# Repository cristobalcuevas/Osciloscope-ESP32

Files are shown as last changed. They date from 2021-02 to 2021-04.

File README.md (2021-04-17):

# Osciloscope with ESP32

This was my project to get my degree :)

It was based on designing a board that could do the acquisition and conditioning of analog signals so that later they would be read by the ESP32 and displayed on a local server within the memory of the ESP32, so that several devices could access through the IP simultaneously.

## Circuit

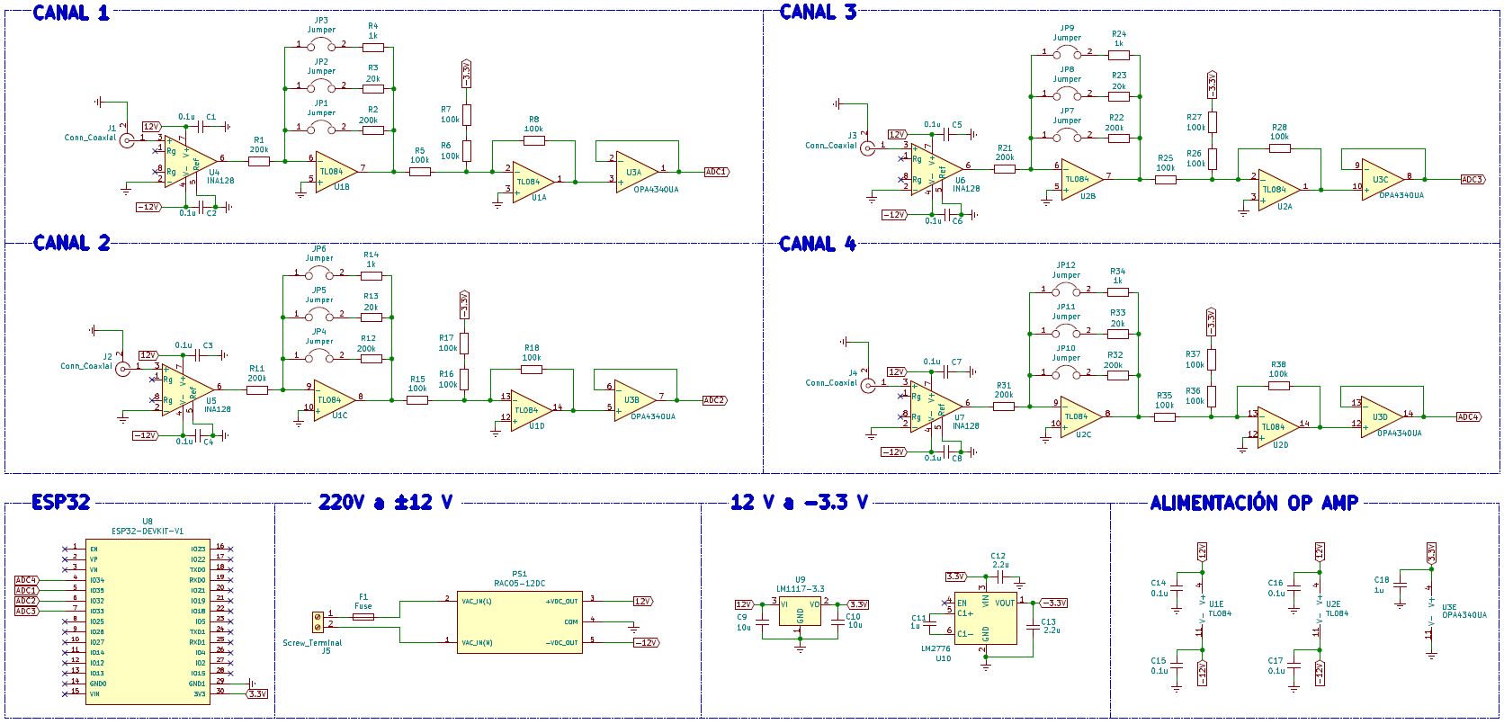
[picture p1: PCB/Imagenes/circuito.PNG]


## PCB Design

### Front Layer
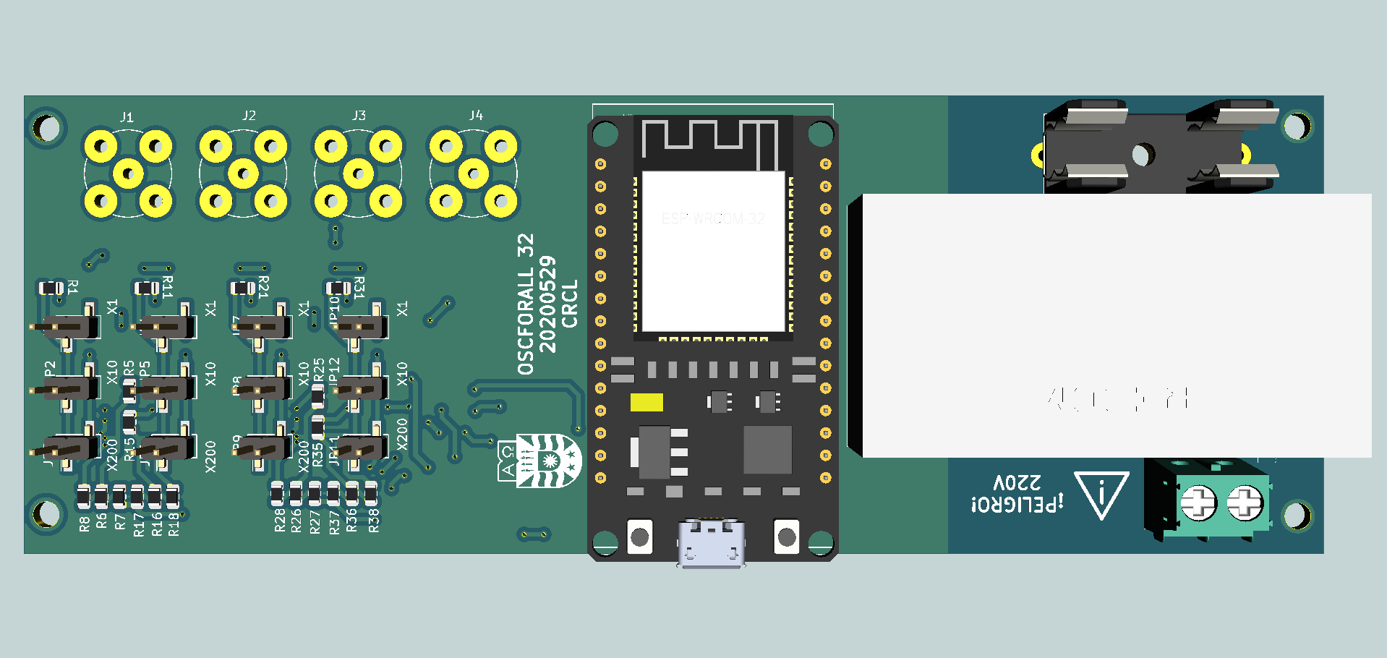
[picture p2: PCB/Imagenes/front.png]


### Back Layer
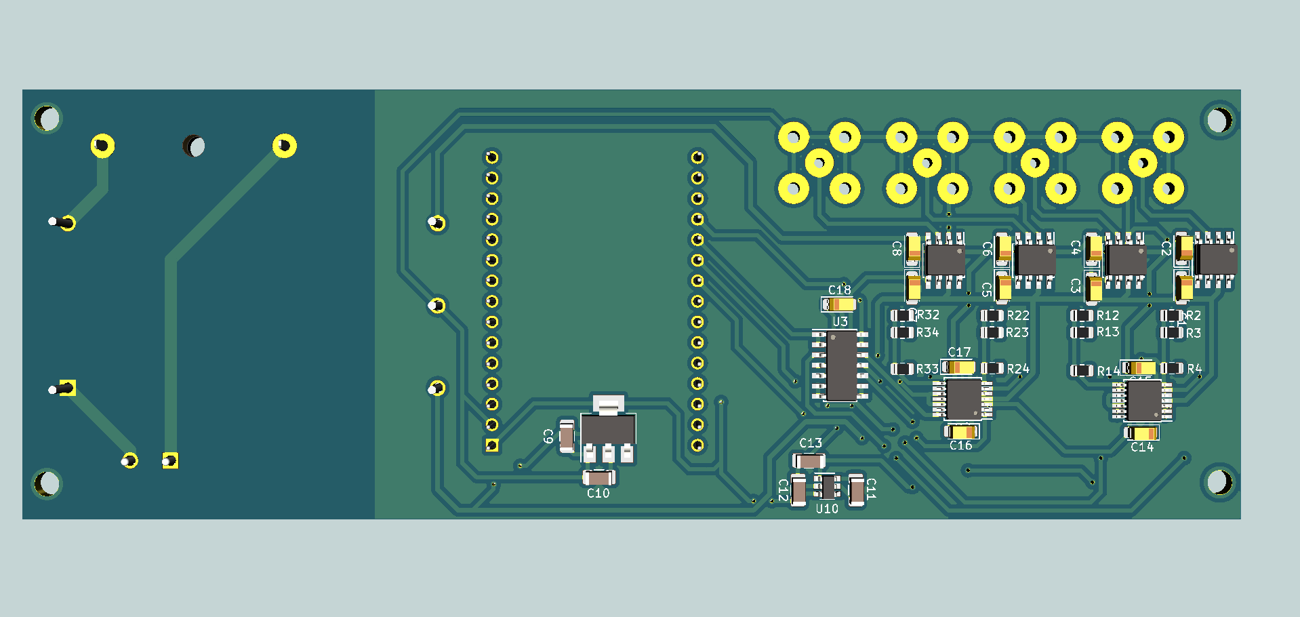
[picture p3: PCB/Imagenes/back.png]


## Video

<a href="https://drive.google.com/file/d/1jKXpbea2SFpHbxWFMag4WS3YogWa_oBE/view?usp=sharing" target="_blank">Video Google Drive</a>

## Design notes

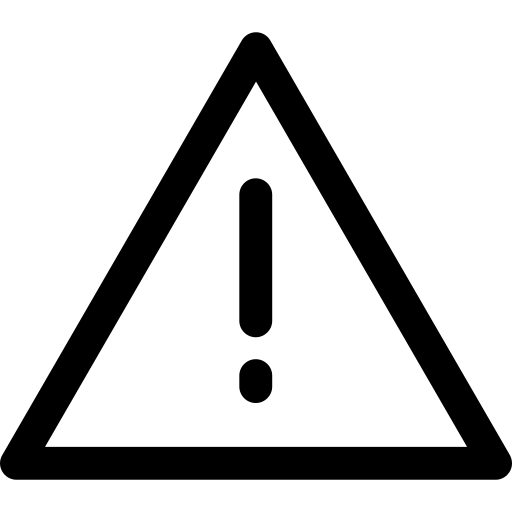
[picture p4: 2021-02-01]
PCB/Graficas/Peligro/Peligro.bmp

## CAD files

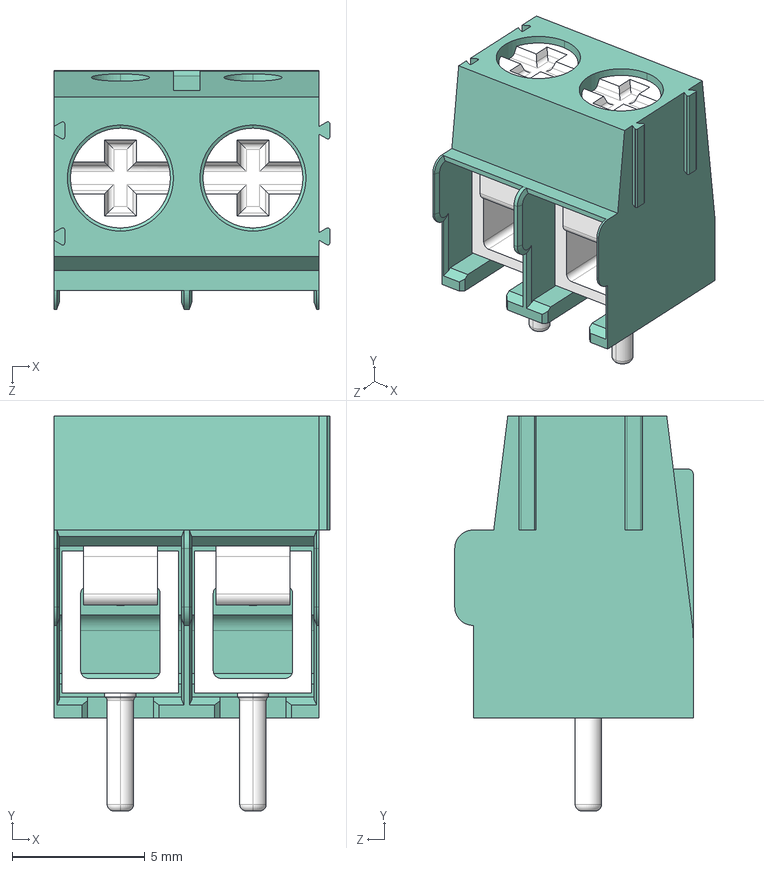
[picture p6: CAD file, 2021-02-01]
PCB/3D/Terminal_Bloc.STEP
10.4 x 14.9 x 9.00 mm

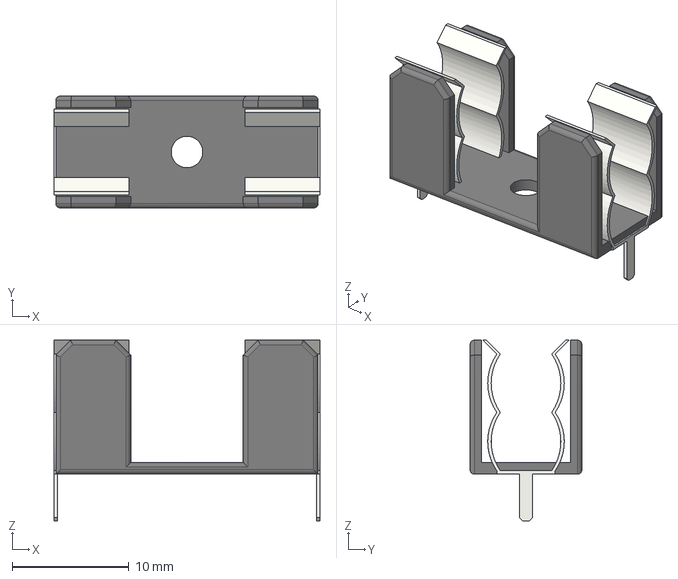
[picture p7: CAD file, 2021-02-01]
PCB/3D/Fuseholder_Cylinder-5x20mm_Schurter_0031_8201_Horizontal_Open.step
22.8 x 9.60 x 15.5 mm

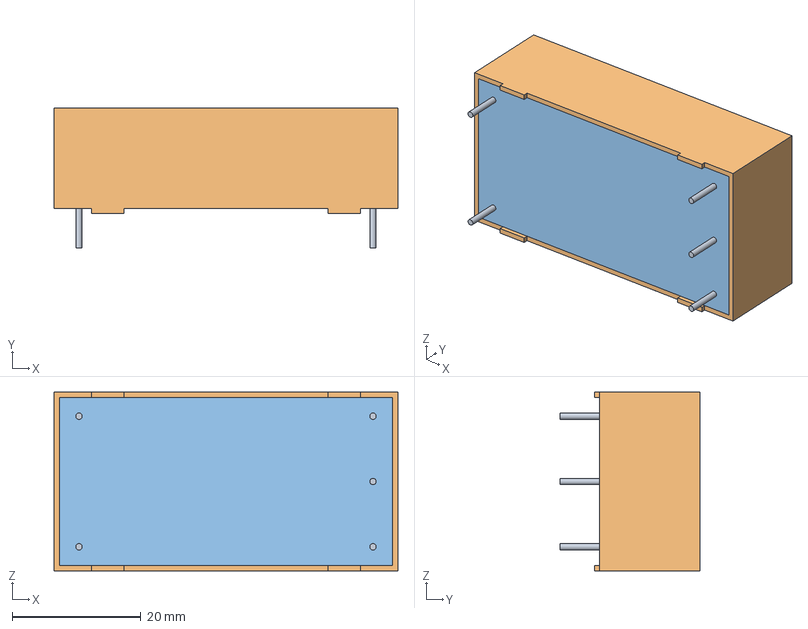
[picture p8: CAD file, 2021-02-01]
PCB/3D/RAC05_15DC.STEP
53.5 x 21.8 x 27.8 mm

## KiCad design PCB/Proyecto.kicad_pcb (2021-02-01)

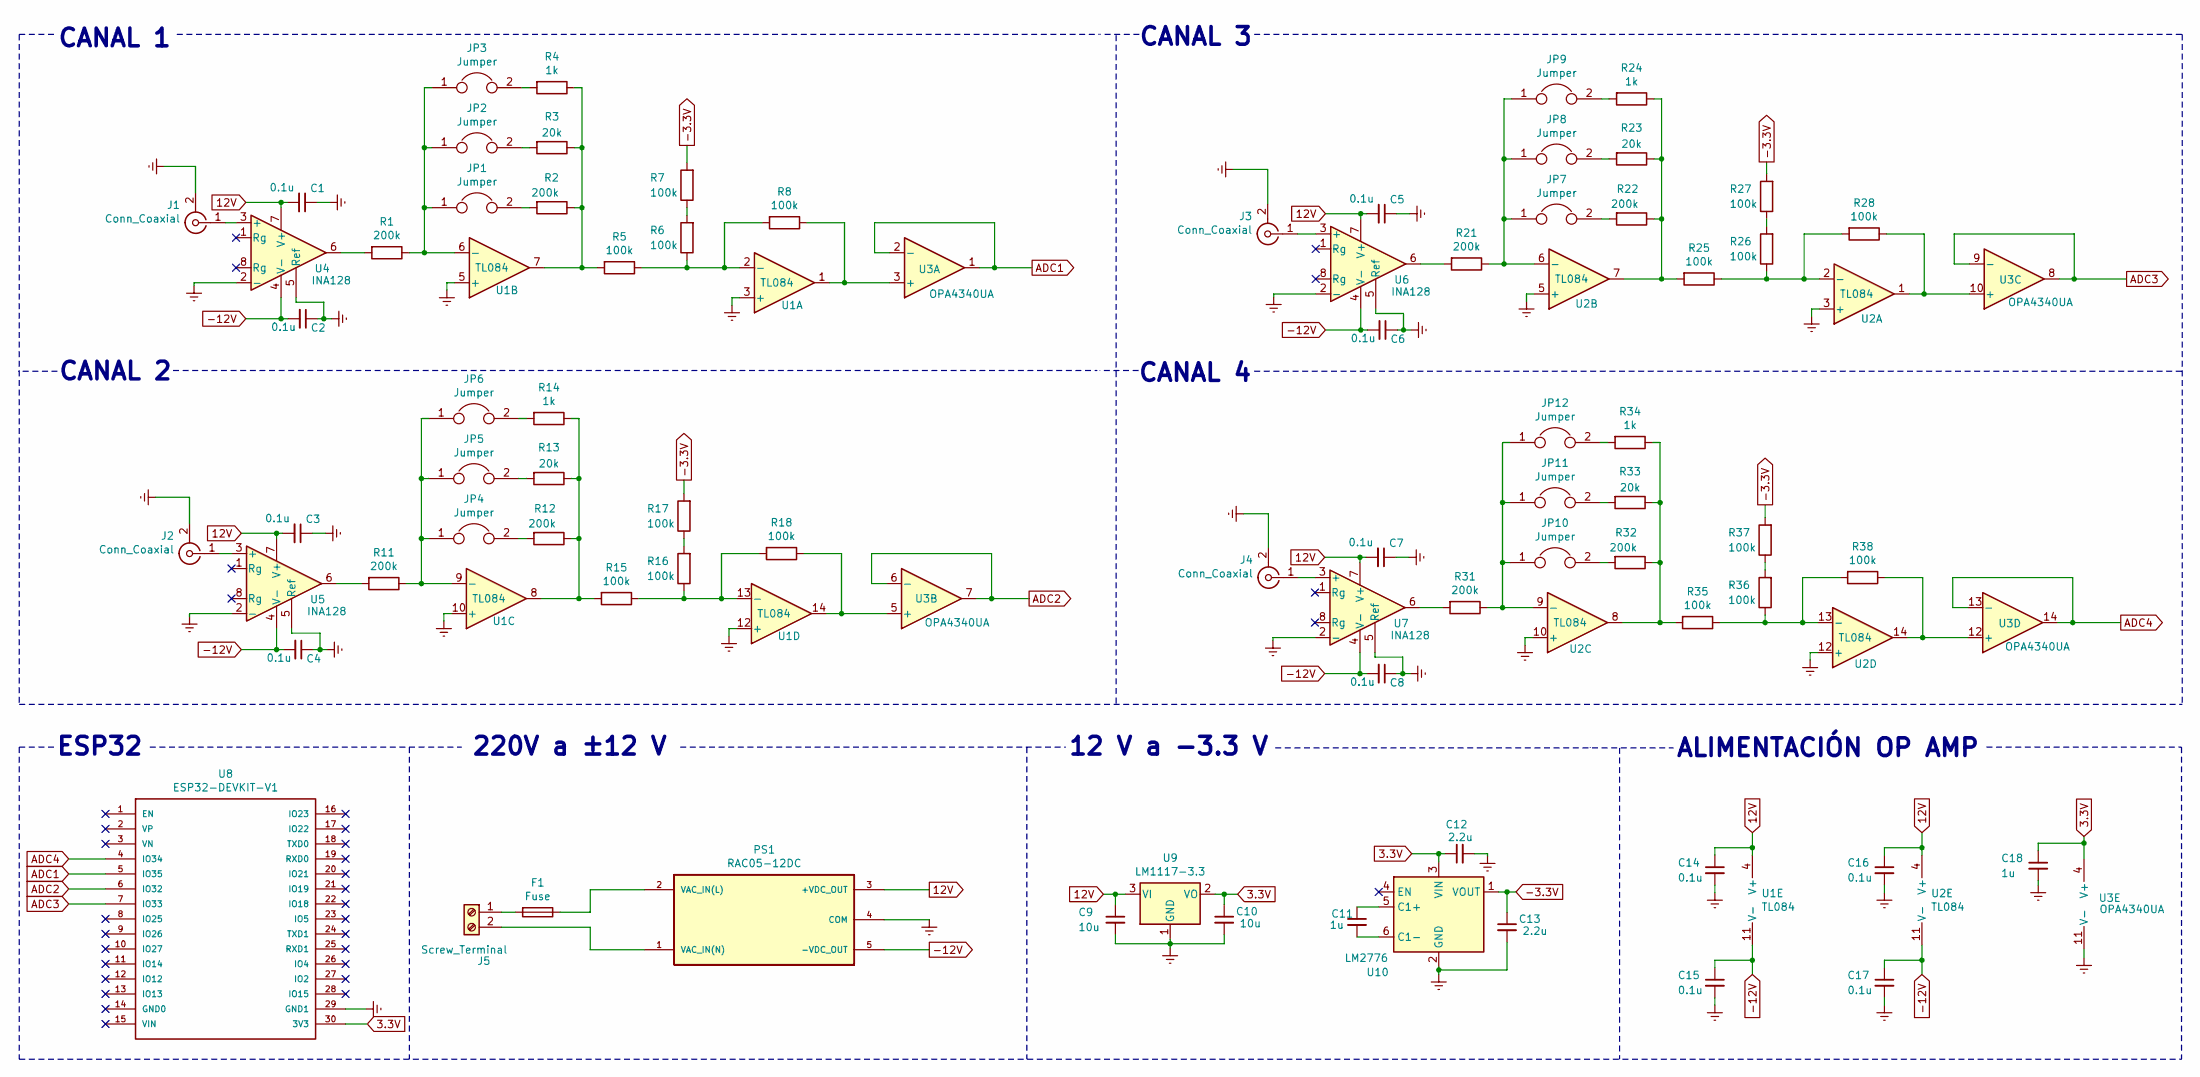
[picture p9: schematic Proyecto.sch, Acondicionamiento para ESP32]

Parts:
C1, C2, C3, C4, C5, C6, C7, C8, C14, C15, C16, C17: 0.1u; CP_EIA-3216-18_Kemet-A; Digikey 399-3677-1-ND
C9: 10u; C_1206_3216Metric; Digikey 399-1043-1-ND
C10: 10u; C_1206_3216Metric; Digikey 399-4873-1-ND
C11: 1u; C_1206_3216Metric; Digikey 478-8995-1-ND
C12, C13: 2.2u; C_1206_3216Metric; Digikey 478-13259-1-ND
C18: 1u; CP_EIA-3216-18_Kemet-A; Digikey 399-3677-1-ND
F1: Fuse; Fuseholder_Cylinder-5x20mm_Schurter_0031_8201_Horizontal_Op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; Digikey 507-1286-ND
J1, J2, J3, J4: Conn_Coaxial; BNC_TEConnectivity_1478204_Vertical
J5: Screw_Terminal; Terminal_Block; Digikey 277-6405-ND
JP1, JP2, JP3, JP4, JP5, JP6, JP7, JP8, JP9, JP10, JP11, JP12: Jumper; PinHeader_1x02_P2.54mm_Vertical_SMD_Pin1Left
PS1: RAC05-12DC; RAC05_12DC
R1, R2, R11, R12, R21, R22, R31, R32: 200k; R_0805_2012Metric
R3, R13, R23, R33: 20k; R_0805_2012Metric
R4, R14, R24, R34: 1k; R_0805_2012Metric
R5, R6, R7, R8, R15, R16, R17, R18, R25, R26, R27, R28, R35, R36, R37, R38: 100k; R_0805_2012Metric
U1, U2: TL084; TSSOP-14_4.4x5mm_P0.65mm
U3: OPA4340UA; SOIC-14_3.9x8.7mm_P1.27mm
U4, U5, U6, U7: INA128; SOIC-8_3.9x4.9mm_P1.27mm
U8: ESP32-DEVKIT-V1; ESP_32
U9: LM1117-3.3; SOT-223-3_TabPin2
U10: LM2776; SOT-23-6

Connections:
3.3V: C10.1, C12.1, C18.1, U3.4 (V+), U8.30 (3V3), U9.2 (VO), U10.3 (VIN)
12V: C1.2, C3.2, C5.2, C7.2, C9.1, C14.1, C16.1, PS1.3 (+VDC_OUT), U1.4 (V+), U2.4 (V+), U4.7 (V+), U5.7 (V+), U6.7 (V+), U7.7 (V+), U9.3 (VI)
-3.3V: C13.1, R7.2, R17.2, R27.2, R37.2, U10.1 (VOUT)
-12V: C2.2, C4.2, C6.2, C8.2, C15.1, C17.1, PS1.5 (-VDC_OUT), U1.11 (V-), U2.11 (V-), U4.4 (V-), U5.4 (V-), U6.4 (V-), U7.4 (V-)
ADC1: U3.1, U3.2 (-), U8.5 (IO35)
ADC2: U3.6 (-), U3.7, U8.6 (IO32)
ADC3: U3.8, U3.9 (-), U8.7 (IO33)
ADC4: U3.13 (-), U3.14, U8.4 (IO34)
Earth: C1.1, C2.1, C3.1, C4.1, C5.1, C6.1, C7.1, C8.1, C9.2, C10.2, C12.2, C13.2, C14.2, C15.2, C16.2, C17.2, C18.2, J1.2 (Ext), J2.2 (Ext), J3.2 (Ext), J4.2 (Ext), PS1.4 (COM), U1.3 (+), U1.5 (+), U1.10 (+), U1.12 (+), U2.3 (+), U2.5 (+), U2.10 (+), U2.12 (+), U3.11 (V-), U4.2 (-), U4.5 (Ref), U5.2 (-), U5.5 (Ref), U6.2 (-), U6.5 (Ref), U7.2 (-), U7.5 (Ref), U8.29 (GND1), U9.1 (GND), U10.2 (GND)
unnamed: C11.1, U10.5 (C1+)
unnamed: C11.2, U10.6 (C1-)
unnamed: F1.1, PS1.2 (VAC_IN(L))
unnamed: F1.2, J5.1
unnamed: J1.1 (In), U4.3 (+)
unnamed: J2.1 (In), U5.3 (+)
unnamed: J3.1 (In), U6.3 (+)
unnamed: J4.1 (In), U7.3 (+)
unnamed: J5.2, PS1.1 (VAC_IN(N))
unnamed: JP1.1, JP2.1, JP3.1, R1.1, U1.6 (-)
unnamed: JP1.2, R2.2
unnamed: JP2.2, R3.2
unnamed: JP3.2, R4.2
unnamed: JP4.1, JP5.1, JP6.1, R11.1, U1.9 (-)
unnamed: JP4.2, R12.2
unnamed: JP5.2, R13.2
unnamed: JP6.2, R14.2
unnamed: JP7.1, JP8.1, JP9.1, R21.1, U2.6 (-)
unnamed: JP7.2, R22.2
unnamed: JP8.2, R23.2
unnamed: JP9.2, R24.2
unnamed: JP10.1, JP11.1, JP12.1, R31.1, U2.9 (-)
unnamed: JP10.2, R32.2
unnamed: JP11.2, R33.2
unnamed: JP12.2, R34.2
unnamed: R1.2, U4.6
unnamed: R2.1, R3.1, R4.1, R5.2, U1.7
unnamed: R5.1, R6.1, R8.2, U1.2 (-)
unnamed: R6.2, R7.1
unnamed: R8.1, U1.1, U3.3 (+)
unnamed: R11.2, U5.6
unnamed: R12.1, R13.1, R14.1, R15.2, U1.8
unnamed: R15.1, R16.1, R18.2, U1.13 (-)
unnamed: R16.2, R17.1
unnamed: R18.1, U1.14, U3.5 (+)
unnamed: R21.2, U6.6
unnamed: R22.1, R23.1, R24.1, R25.2, U2.7
unnamed: R25.1, R26.1, R28.2, U2.2 (-)
unnamed: R26.2, R27.1
unnamed: R28.1, U2.1, U3.10 (+)
unnamed: R31.2, U7.6
unnamed: R32.1, R33.1, R34.1, R35.2, U2.8
unnamed: R35.1, R36.1, R38.2, U2.13 (-)
unnamed: R36.2, R37.1
unnamed: R38.1, U2.14, U3.12 (+)

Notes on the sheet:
CANAL 1
CANAL 3
CANAL 4
220V a ±12 V
12 V a -3.3 V
ESP32
CANAL 2
ALIMENTACIÓN OP AMP

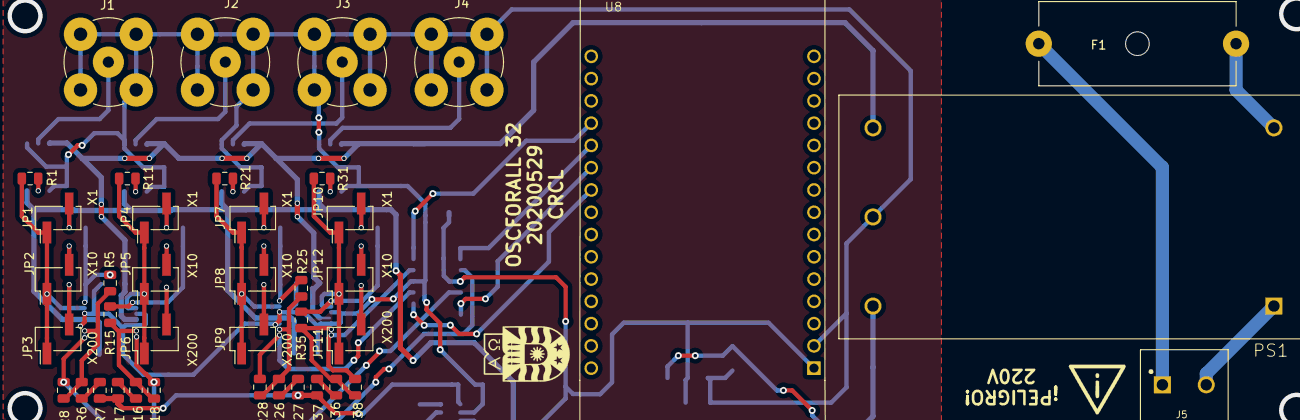
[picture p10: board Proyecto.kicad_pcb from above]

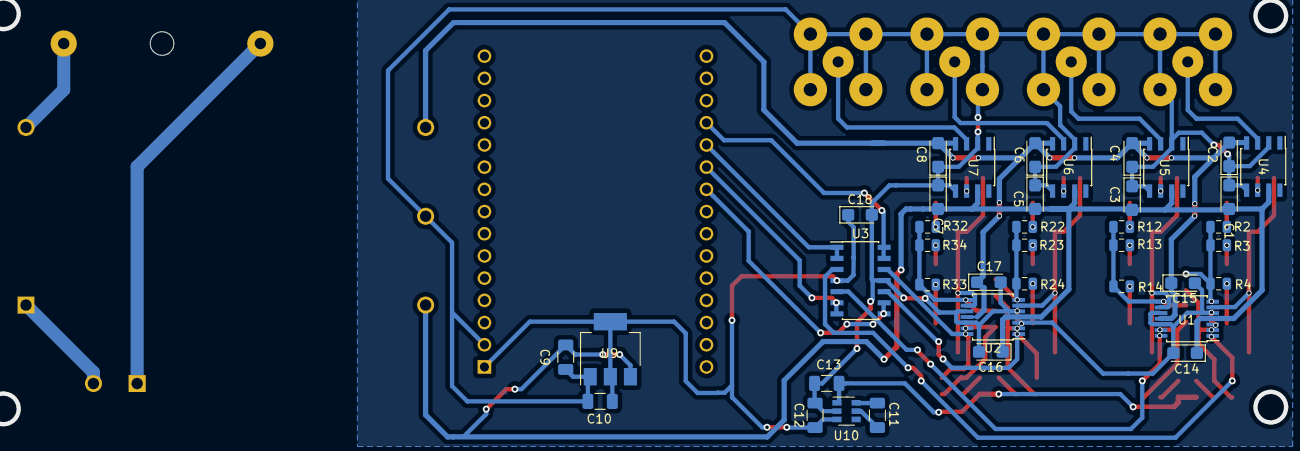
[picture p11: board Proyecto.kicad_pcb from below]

Board: 2 copper layers, 79 parts (39 on the bottom side), 54 nets.

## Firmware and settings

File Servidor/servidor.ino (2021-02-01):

/*************** LIBRERIAS *****************/
#include <WiFi.h>
#include <ESPAsyncWebServer.h>
#include <SPIFFS.h>
AsyncWebServer server(80);
/*************** ARCHIVOS ******************/
#include "utilidades.hpp"
#include "servidor.hpp"
/***************** SETUP *******************/
void setup(void) {
  Serial.begin(115200);
  SPIFFS.begin();
  ConnectWiFi_STA();
  InitServer();
}
/***************** LOOP ********************/
void loop() {}

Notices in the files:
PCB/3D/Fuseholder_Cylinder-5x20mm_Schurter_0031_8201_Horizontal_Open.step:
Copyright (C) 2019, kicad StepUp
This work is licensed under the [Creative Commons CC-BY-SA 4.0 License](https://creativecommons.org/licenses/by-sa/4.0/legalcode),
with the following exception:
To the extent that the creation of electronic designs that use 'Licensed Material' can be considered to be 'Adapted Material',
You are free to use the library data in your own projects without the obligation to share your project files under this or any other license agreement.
